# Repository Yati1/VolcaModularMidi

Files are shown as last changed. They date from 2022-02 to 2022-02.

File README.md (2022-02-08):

# VolcaModularMidi

The [original Volca midi project](https://github.com/sensai7/VolcaModularMidi) seemed to have a glitch where after a few seconds of playing the volca will get stuck on a single-note. After some investigating I found that [this way of wiring up the octocoupler fixed the issue](https://hackaday.com/tag/6n137/). 

This is a hardware mod to add MIDI IN capability to the [Korg Volca Modular](https://www.korg.com/us/products/dj/volca_modular/)

Board

## Schematic

Board

## Bill Of Materials:
 * R1  220 ohm resistor
 * R2  270 ohm resistor
 * D1  1N4148 diode
 * J1  2.54mm header
 * J2  DIN-5 connector
 * U1  6n139 optocoupler (6n138 and 6n137 should also work as well)

## How to install:

BEFORE YOU BEGIN: 

* This installation process requires you to open your Korg volca Modular, most likely voiding the warranty. The creator of this mod and all the contributors of this project are not to be held responsible for possible malfunctions caused by this process.

* In these example photos the mod was already installed (the red/orange/yellow/green cables), but I repeated the process to take the photos and make it easier to explain.

* Read the tutorial and make sure you understand all the steps before proceeding.

Be sure to have the following tools:
  * M3 screwdriver
  * Flat screwdriver (not absolutely necessary but it's useful to unplug the ribbon connectors)
  * Pliers or something to snip and cut thin cables
  * A dril or any tool to open a hole in the case

1-	Unscrew the screws from the back.
Board

2-	Gently pull from a potentiometer to detach the blue case from the circuit.
Board

3-	Unplug the batteries connector (red/black cables) in the top right of the board
Board

4-	Lay the circuit down, be careful with the speaker connection (orange/brown cables)
Board

5-	You can see the holes now, they're labelled as MIDI_RX, MIDI_TX, +3.3V, GND
Board

6-	Unpeel the black tape and unplug the keyboard connector (white/orange cables)
Board
Board

7-	Unscrew the 6 screws attaching the main board with the keyboard board.
Board

8-	Sit the main board on it's place in the blue case and open a hole on the right side enough to let the four cables go through. Then solder the four cables facing down and snip the excess wire. (disregard the quality of mine, I don't have the tools nor skill for these things :( )
Board

9-	Repeat the process from steps 7 to 1 in inverse order to reassemble the unit.

## Mod mods

If you have the tools, and patience, you can glue the female connections to the case so you can plug it directly (here's a poorly photoshopped concept illustrating it)
Board

If you prefer to use a 3.5mm stereo jack instead of the big DIN-5 connector, here's another poorly photoshopped concept
Board

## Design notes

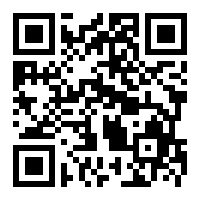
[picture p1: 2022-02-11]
projectURL.png

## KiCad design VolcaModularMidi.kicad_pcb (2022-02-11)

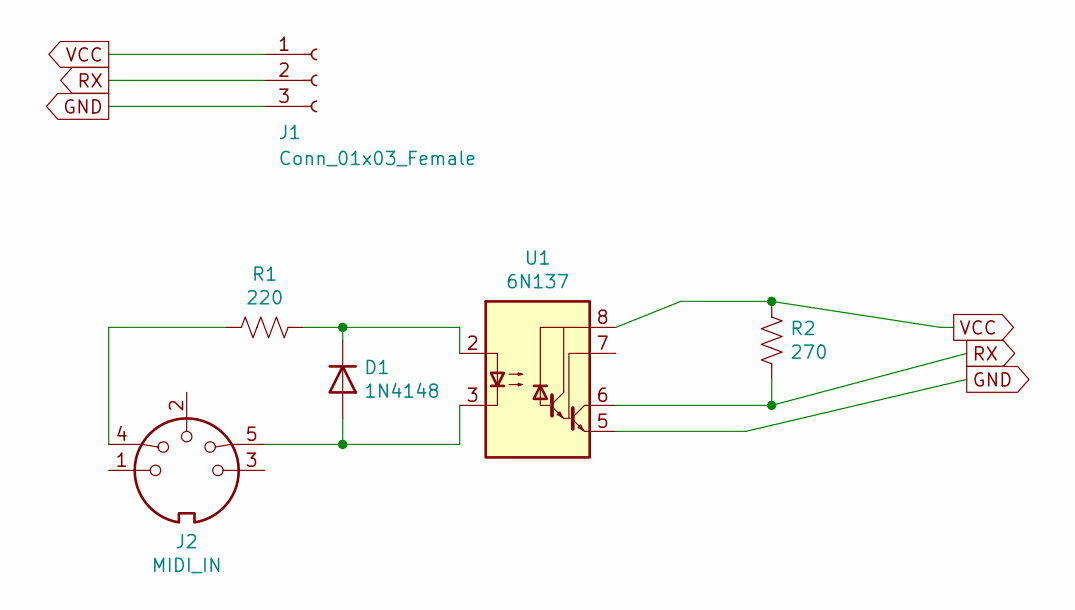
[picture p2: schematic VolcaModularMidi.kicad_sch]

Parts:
D1: 1N4148; D_DO-35_SOD27_P7.62mm_Horizontal
J1: Conn_01x03_Female; JST_EH_B3B-EH-A_1x03_P2.50mm_Vertical
J2: MIDI_IN; MIDI_DIN5
R1: 220; R_Axial_DIN0207_L6.3mm_D2.5mm_P7.62mm_Horizontal
R2: 270; R_Axial_DIN0207_L6.3mm_D2.5mm_P7.62mm_Horizontal
U1: 6N137; DIP-8_W7.62mm_LongPads

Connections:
GND: J1.3, U1.5 (GND)
unnamed: D1.1 (K), R1.1, U1.2 (C1)
unnamed: D1.2 (A), J2.5, U1.3 (C2)
unnamed: J2.4, R1.2
RX: J1.2, R2.2, U1.6 (VO2)
VCC: J1.1, R2.1, U1.8 (VCC)

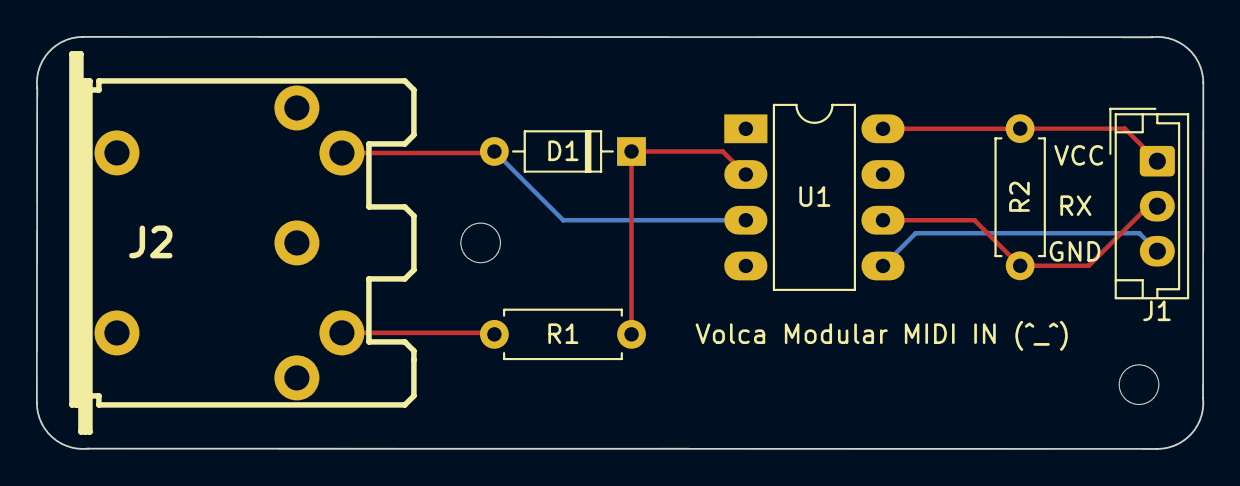
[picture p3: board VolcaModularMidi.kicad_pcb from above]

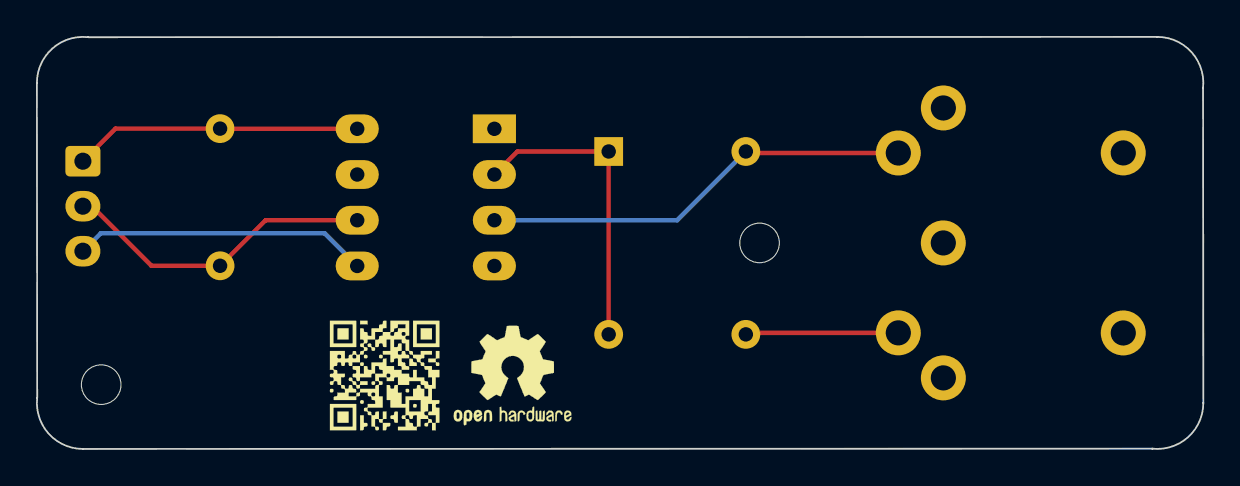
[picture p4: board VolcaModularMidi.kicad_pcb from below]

Board: 2 copper layers, 64.8 x 22.9 mm, 8 parts (2 on the bottom side), 6 nets.

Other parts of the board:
 : volcaMidiProjUrl
 #2: OSHW-Logo2_7.3x6mm_SilkScreen

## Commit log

2022-02-08 Edited schematic with my fix
    [VolcaModularMidi.kicad_sch]
2022-02-10 Finished routing and laying out pcb
    [VolcaModularMidi.kicad_pcb, VolcaModularMidi.kicad_sch]
2022-02-11 Deleting old project files
    [VolcaModularMidi-B.Cu.gbr, VolcaModularMidi-B.Mask.gbr, VolcaModularMidi-B.Paste.gbr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]
2022-02-11 Added mounting holes, replaced jumper connector with jst connector
    [VolcaModularMidi.kicad_pcb, VolcaModularMidi.kicad_sch]
2022-02-11 Added URL QR code
    [VolcaModularMidi.kicad_pcb]
2022-02-11 Generated gerbers and drill files
    [VolcaModularMidi-B_Cu.gbr, VolcaModularMidi-B_Mask.gbr, VolcaModularMidi-B_Paste.gbr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]
